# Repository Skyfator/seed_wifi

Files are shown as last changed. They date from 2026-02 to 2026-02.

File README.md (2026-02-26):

# seed_wifi

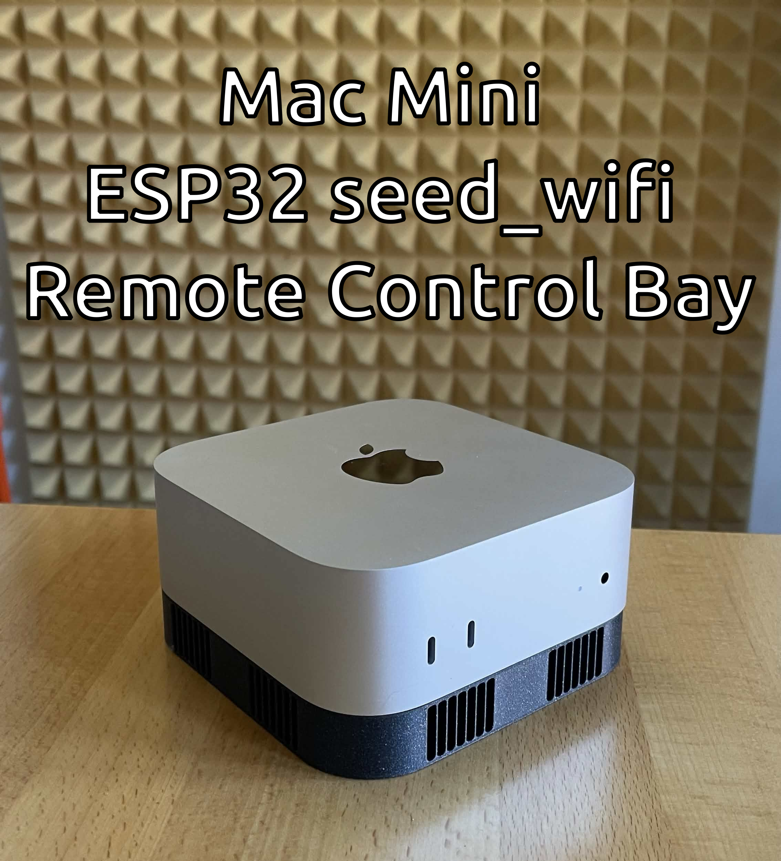
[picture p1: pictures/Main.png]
Main


Remote Mac Mini power control and keyboard input via ESP32S3 over WireGuard VPN.

Fork of [phokz/seed_wifi](https://github.com/phokz/seed_wifi).

---

## What it does

The ESP32S3 sits inside a 3D-printed enclosure physically mounted over the Mac Mini's power button. It connects to your WiFi and exposes an HTTP API through a WireGuard VPN tunnel. You can:

- **Turn the Mac Mini on** — servo smoothly presses the power button and releases
- **Turn the Mac Mini off** — servo presses and holds the power button for 11 seconds (force shutdown)
- **Type text** — injects keystrokes via USB HID (passwords, commands, etc.)

---

## Hardware

- Seeed XIAO ESP32S3
- Generic UFL dual band antenna
- SG90 180° servo on pin **D10**
- 3D-printed enclosure ([MiniMacBay.stl](stl/MiniMacBay.stl)) — also available as [STEP](stl/bay.step) — Fusion 360 source: [Bay-fusion project.f3z](stl/Bay-fusion%20project.f3z)
- USB-C cable

| | |
|---|---|
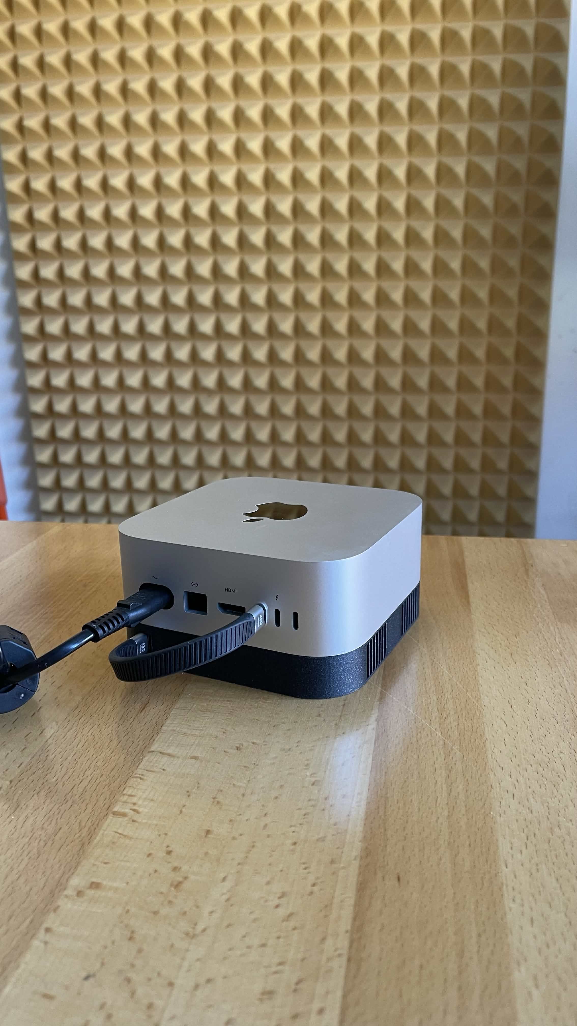
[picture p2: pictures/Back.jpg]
Back
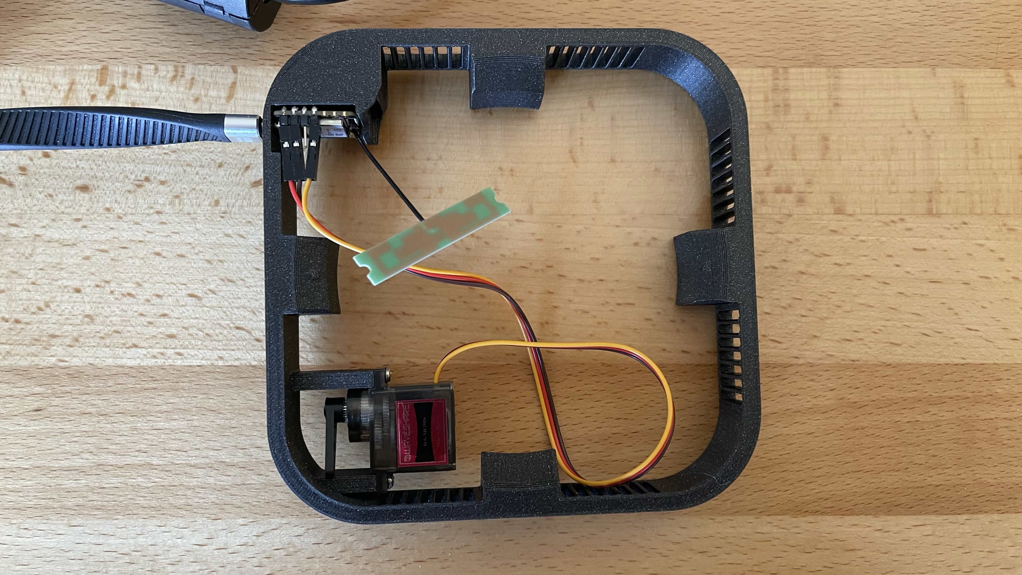
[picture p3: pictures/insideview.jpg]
Inside
|  |  |

---

## API

All endpoints on port 80 of the WireGuard IP. Protected with `X-Auth` header if token is set.

| Method | Endpoint | Body | Description |
|---|---|---|---|
| POST | `/power-on` | — | Press power button (turns Mac on) |
| POST | `/power-off` | — | Hold power button 11s (force shutdown) |
| POST | `/keys` | `keys=<text>` | Type text via USB HID |
| GET | `/health` | — | WiFi + WireGuard status |

### Examples

```bash
# Turn on
curl -X POST http://100.64.0.10/power-on -H "X-Auth: yourtoken"

# Force off
curl -X POST http://100.64.0.10/power-off -H "X-Auth: yourtoken"

# Type a password
curl -X POST http://100.64.0.10/keys -d "keys=mypassword" -H "X-Auth: yourtoken"

# Check status
curl http://100.64.0.10/health
```

---

## Build

All config is passed as compiler flags — no secrets in source code.

```bash
arduino-cli compile \
  --fqbn esp32:esp32:XIAO_ESP32S3 \
  -D WIFI_SSID=\"your-ssid\" \
  -D WIFI_PASS=\"your-password\" \
  -D WG_PRIVATE_KEY=\"your-wg-private-key\" \
  -D WG_LOCAL_IP=\"100.64.0.10\" \
  -D WG_PEER_PUBLIC_KEY=\"peer-public-key\" \
  -D WG_PEER_HOST=\"wg.yourdomain.com\" \
  -D WG_PEER_PORT=51820 \
  -D HTTP_AUTH_TOKEN=\"yourtoken\" \
  seed_wifi/

arduino-cli upload -p /dev/ttyACM0 --fqbn esp32:esp32:XIAO_ESP32S3 seed_wifi/
```

---

## Servo tuning

Adjust these constants at the top of `seed_wifi.ino` to match your physical mounting:

```cpp
const int START_US = ...;              // resting position (move the servo arm where its touching the brace on the model (7°by default, edit if nescesarry)
const int END_US   = ...;              // fully pressed position (30°by default, edit if nescesarry)
const unsigned long SWEEP_MS = 3000;  // how long the press (on) movement takes
const unsigned long HOLD_MS  = 11000; // how long to hold until moving back to the resting position - used for turning the mac mini off)
```

---

## WireGuard setup

Uses [WireGuard-ESP32-Arduino](https://github.com/robhany/WireGuard-ESP32-Arduino). Generate a key pair for the device:

```bash
wg genkey | tee privatekey | wg pubkey > publickey
```

Add the device as a peer on your WireGuard server, then pass the keys as build flags.

---

## Upload procedure (Linux)

1. On your ESP32, hold **BOOT**, tap **RESET**, release **BOOT**
2. `sudo chmod a+rw /dev/ttyACM0`
3. Run the upload command above
4. Press **RESET** to boot into the new firmware

Permanent fix: `sudo usermod -a -G dialout $USER` (requires logout/login)

---

## Known issue: power loss on shutdown

When the Mac Mini shuts down, its USB ports lose power — taking the ESP32 with it, making remote power-on impossible. Fix with either a small LiPo on the battery connector, or an always-on external USB power source with a diode wired in series.

---

## Security

This device can type anything on the computer it's plugged into. Treat it like root access. Keep the WireGuard private key secret and always set an `HTTP_AUTH_TOKEN`.

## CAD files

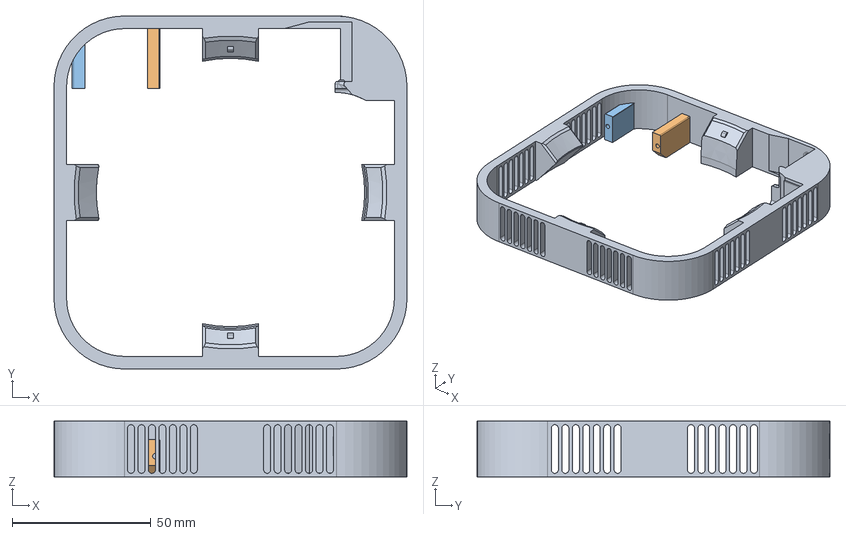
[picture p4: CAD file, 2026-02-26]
stl/bay.step
127.0 x 127.0 x 20.0 mm

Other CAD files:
stl/MiniMacBay.stl
stl/Bay-fusion project.f3z

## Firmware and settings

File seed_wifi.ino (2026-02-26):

#include <WiFi.h>
#include <WebServer.h>
#include <WireGuard-ESP32.h>
#include <ESP32Servo.h>
#include "USB.h"
#include "USBHIDKeyboard.h"

USBHIDKeyboard Keyboard;
static WireGuard wg;
WebServer server(80);
Servo myServo;

const int SERVO_PIN  = 9;
const int US_MIN     = 500;
const int US_MAX     = 2500;
const int START_US   = US_MIN + (int)(7.0  * 2000.0 / 180.0);
const int END_US     = US_MIN + (int)(30.0 * 2000.0 / 180.0);
const unsigned long SWEEP_MS = 3000;

void sweepToEnd() {
  unsigned long t0 = millis();
  while (true) {
    unsigned long elapsed = millis() - t0;
    if (elapsed >= SWEEP_MS) break;
    float progress = (float)elapsed / SWEEP_MS;
    int us = START_US + (int)(progress * (END_US - START_US));
    myServo.writeMicroseconds(us);
    delay(20);
  }
  myServo.writeMicroseconds(END_US);
}

#if __has_include("secrets.h")
  #include "secrets.h"
#endif

#ifndef WIFI_SSID
  #define WIFI_SSID "essid"
#endif
#ifndef WIFI_PASS
  #define WIFI_PASS "wifipass"
#endif
#ifndef WG_PRIVATE_KEY
  #define WG_PRIVATE_KEY "YOUR_PRIVATE_KEY_HERE"
#endif
#ifndef WG_LOCAL_IP
  #define WG_LOCAL_IP "100.64.0.10"
#endif
#ifndef WG_PEER_PUBLIC_KEY
  #define WG_PEER_PUBLIC_KEY "PEER_PUBLIC_KEY_HERE"
#endif
#ifndef WG_PEER_HOST
  #define WG_PEER_HOST "wg.domain.tld"
#endif
#ifndef WG_PEER_PORT
  #define WG_PEER_PORT 51820
#endif
#ifndef HTTP_AUTH_TOKEN
  #define HTTP_AUTH_TOKEN ""
#endif

static const bool ADD_ENTER_AFTER_KEYS = true;

#define LED_PIN 21
void ledBlink(int times, int onMs, int offMs) {
  for (int i = 0; i < times; i++) {
    digitalWrite(LED_PIN, HIGH); delay(onMs);
    digitalWrite(LED_PIN, LOW);  delay(offMs);
  }
}

void typeRaw(const String& s) {
  for (size_t i = 0; i < s.length(); i++) {
    Keyboard.write((uint8_t)s[i]);
  }
}

bool authOk() {
  if (String(HTTP_AUTH_TOKEN).length() == 0) return true;
  if (!server.hasHeader("X-Auth")) return false;
  return server.header("X-Auth") == String(HTTP_AUTH_TOKEN);
}

void handleKeys() {
  if (!authOk()) { server.send(401, "text/plain", "unauthorized\n"); return; }
  String keys = server.arg("keys");
  if (keys.length() == 0) { server.send(400, "text/plain", "missing keys param\n"); return; }
  keys.replace("\r", "");
  keys.replace("\n", "");
  typeRaw(keys);
  if (ADD_ENTER_AFTER_KEYS) Keyboard.write('\n');
  server.send(200, "text/plain", "ok\n");
}

void handlePowerOn() {
  if (!authOk()) { server.send(401, "text/plain", "unauthorized\n"); return; }
  server.send(200, "text/plain", "ok\n");
  // pass 1: sweep to 30°, snap back
  sweepToEnd();
  myServo.writeMicroseconds(START_US);
}

void handlePowerOff() {
  if (!authOk()) { server.send(401, "text/plain", "unauthorized\n"); return; }
  server.send(200, "text/plain", "ok\n");
  // pass 2: sweep to 30°, hold 11s, snap back
  sweepToEnd();
  delay(11000);
  myServo.writeMicroseconds(START_US);
}

void handleHealth() {
  String msg;
  msg += "wifi="    + String(WiFi.isConnected() ? "up" : "down") + "\n";
  msg += "wifi_ip=" + WiFi.localIP().toString() + "\n";
  msg += "wg_ip="   + String(WG_LOCAL_IP) + "\n";
  msg += "peer="    + String(WG_PEER_HOST) + ":" + String(WG_PEER_PORT) + "\n";
  server.send(200, "text/plain", msg);
}

void setup() {
  pinMode(LED_PIN, OUTPUT);
  digitalWrite(LED_PIN, LOW);

  myServo.attach(SERVO_PIN, US_MIN, US_MAX);
  myServo.writeMicroseconds(START_US);
  delay(500);

  USB.begin();
  Keyboard.begin();

  delay(2500);

  // scan first: fast blink while scanning
  WiFi.mode(WIFI_STA);
  WiFi.disconnect();
  delay(100);
  int n = WiFi.scanNetworks();
  bool ssidFound = false;
  for (int i = 0; i < n; i++) {
    if (WiFi.SSID(i) == String(WIFI_SSID)) { ssidFound = true; break; }
  }
  // result: 3 fast = SSID found; 10 fast = SSID NOT found
  ledBlink(ssidFound ? 3 : 10, 80, 80);
  delay(1000);

  // fast blink = trying WiFi
  WiFi.begin(WIFI_SSID, WIFI_PASS);
  while (!WiFi.isConnected()) {
    digitalWrite(LED_PIN, HIGH); delay(150);
    digitalWrite(LED_PIN, LOW);  delay(150);
  }
  ledBlink(3, 100, 100); // 3 quick flashes = WiFi up

  // slow blink = waiting for NTP
  configTime(0, 0, "pool.ntp.org", "time.google.com", "time.cloudflare.com");
  time_t now = 0;
  while (now < 1700000000) {
    digitalWrite(LED_PIN, HIGH); delay(500);
    digitalWrite(LED_PIN, LOW);  delay(500);
    now = time(nullptr);
  }
  ledBlink(3, 300, 150); // 3 slow flashes = NTP up

  IPAddress local;
  local.fromString(WG_LOCAL_IP);
  wg.begin(local, WG_PRIVATE_KEY, WG_PEER_HOST, WG_PEER_PUBLIC_KEY, (uint16_t)WG_PEER_PORT);

  server.collectHeaders(new const char*[1]{"X-Auth"}, 1);
  server.on("/power-on",  HTTP_POST, handlePowerOn);
  server.on("/power-off", HTTP_POST, handlePowerOff);
  server.on("/keys",      HTTP_POST, handleKeys);
  server.on("/health",    HTTP_GET,  handleHealth);
  server.onNotFound([]() { server.send(404, "text/plain", "not found\n"); });
  server.begin();

  digitalWrite(LED_PIN, HIGH); // solid = fully up
}

void loop() {
  server.handleClient();
}

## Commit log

2026-02-25 Add servo power control for Mac Mini remote operation
    - Added ESP32Servo for physical power button control via servo on D10
    - POST /power-on: smooth servo press + snap back (turns Mac on)
    - POST /power-off: smooth servo press + 11s hold + snap back (force shutdown)
    - Cleaned up codebase, removed debug mode
    - Updated README with full API docs, build instructions, servo tuning guide
    [seed_wifi.ino]
2026-02-25 Add WireGuard-ESP32-Arduino as submodule
2026-02-26 Add servo control and LED diagnostics; fix WiFi SSID for 2.4GHz
    - Integrate ESP32Servo: GPIO9, 7°→30° sweep, /power-on and /power-off endpoints
    - Add LED diagnostics on GPIO21 for boot stage visibility
    - Add WiFi network scan to detect SSID before connecting
    - Fix: SSID was 5GHz-only; 2.4GHz network has different name
    - gitignore wg-esp32.conf
    [seed_wifi.ino]
2026-02-26 Add stl/ and pictures/ folders; update hardware list in README
2026-02-26 Add photos, STL, and Fusion 360 source; update README with images
    [Bay-fusion project.f3z, MiniMacBay.stl]
2026-02-26 Add STEP file and link in README
    [bay.step]
2026-02-26 Add known issue: USB power loss on shutdown with fix options
